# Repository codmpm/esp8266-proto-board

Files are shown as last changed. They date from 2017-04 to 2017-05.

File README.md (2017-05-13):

# ESP8266 minimal proto board / breadboard adaptor

This is a simple yet useful breadboard adaptor for the all famous ESP8266.

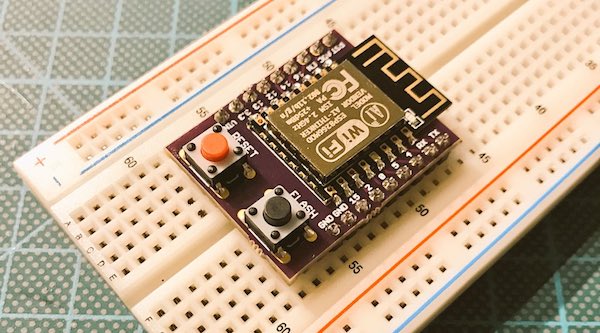
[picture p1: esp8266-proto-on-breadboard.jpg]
esp8266 proto board on breadboard


I've built this as the cheap chinese ones (white boards) are to wide to fit on a regular breadboard. To develop an own design you often don't need a full grown [Adafruit Huzzah](https://www.adafruit.com/product/2471), [Olimex MOD-WIFI-ESP8266-DEV](https://www.olimex.com/Products/IoT/MOD-WIFI-ESP8266-DEV/open-source-hardware) or similar ESP8266 devboard. Also the cheap chinese ones don't have a reset and/or flash button. I don't want to wire the needed resistors and a flash/reset button every time I'm putting an ESP on a breadboard.

Inside the folders you'll find the Eagle schematics and board files.

## Schematics
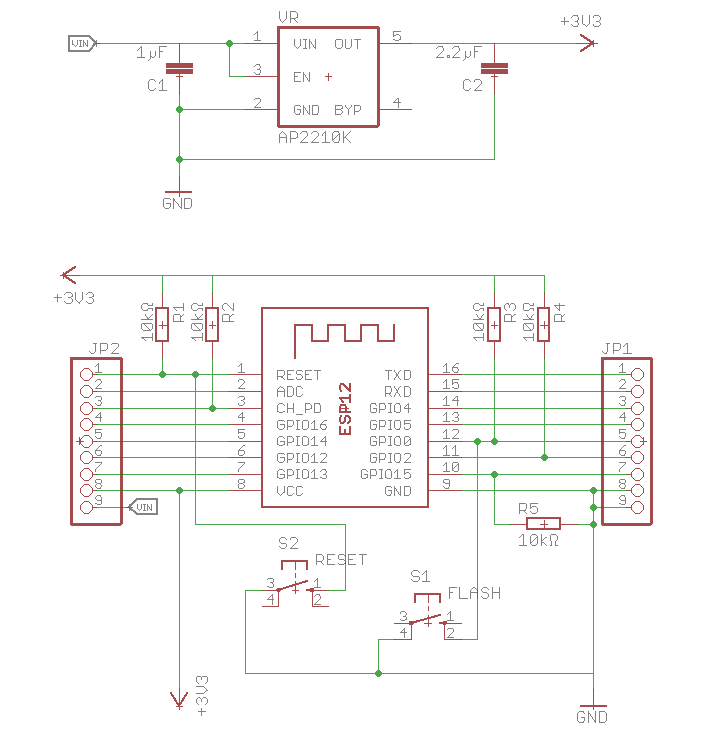
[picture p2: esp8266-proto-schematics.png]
esp8266 proto schematics


## Get it working...
You can simply solder some male headers and an ESP-12(E/F/Q), ESP-07 or ESP-14 on top of the board and are ready to go. 

The better way will be to at least solder some `10kΩ` resistors (`R1-R5`) to have the needed pull-ups/pull-downs to get the ESP working. Obviously it is also a good idea to solder the two push buttons so you have the reset and flash functionality. Then power it up with 3.3 Volts and you are good to go.

The buttons are the very common 6x6mm variant which goes by `switch-omron`. In Germany you can source the from [Reichelt](https://www.reichelt.de/Kurzhubtaster/TASTER-9302/3/index.html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) for example. But every electronics shop should have them in stock.

Optionally you can solder an [LDO](https://en.wikipedia.org/wiki/Low-dropout_regulator) to power the ESP with more than 3.3 Volts, as shown on the left side:

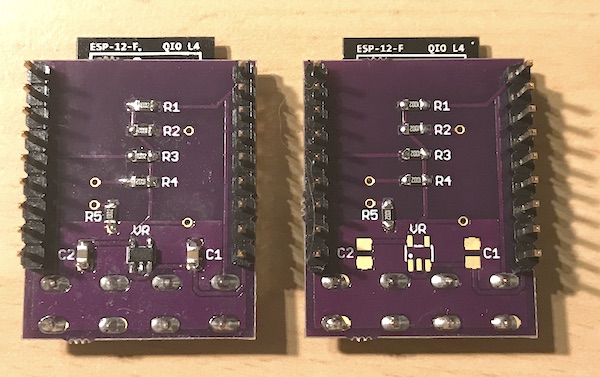
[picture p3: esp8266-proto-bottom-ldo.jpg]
esp8266 proto with and without ldo


## 0805 Version

You'll need 5 x SMD 0805 `10kΩ` resistors (`R1-R5`) and the two push-buttons. The 0805 resistors should be available from your prefered electronic store.

If you want to use the LDO you need the [AP2210K](https://www.diodes.com/assets/Datasheets/AP2210.pdf), a `SOT-23-5` LDO which can be powered with up to 13.2 Volts and only needs two capacitors (`C1/C2`) to run smooth. `C1` is `1µF`, `C2` is `2.2µF` in a 0805 package. It delivers up to 300mA which is fairly enough to power the ESP8266 - you have some room for periphals ;-)

You can use any other `SOT-32-5` LDO which supplies 3.3 Volts with at least 120-150mA, is satisfied with two capacitors and has the same pinout.

The boards can be ordered from [OSH Park](https://oshpark.com/shared_projects/u6mogmdg)



## 1206 Version
This is not finished yet and the repo only holds the work-in-progress version...

## Credits
Patrik Mayer, cod.m GmbH, 2017

Inspired by [tiny ESP8266 breakout](https://github.com/skorokithakis/tiny-ESP8266-breakout) from Stavros Korokithakis

## License
[CC-BY-SA](https://creativecommons.org/licenses/by-sa/3.0/)

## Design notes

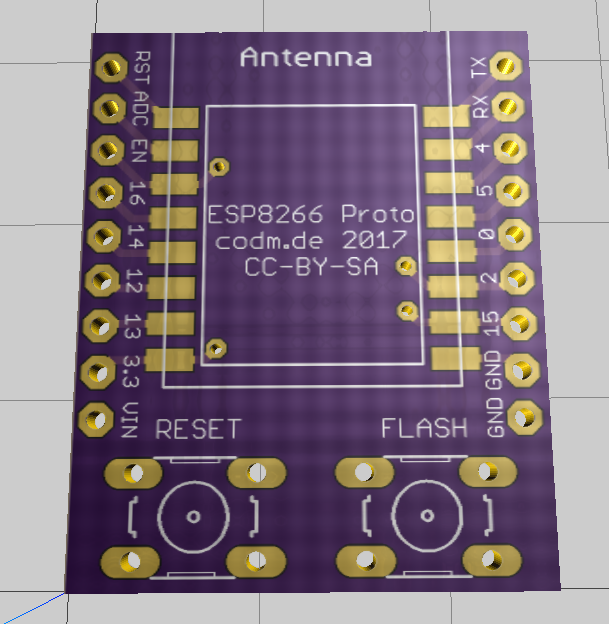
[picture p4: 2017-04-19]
esp8622-proto-board-0805.png

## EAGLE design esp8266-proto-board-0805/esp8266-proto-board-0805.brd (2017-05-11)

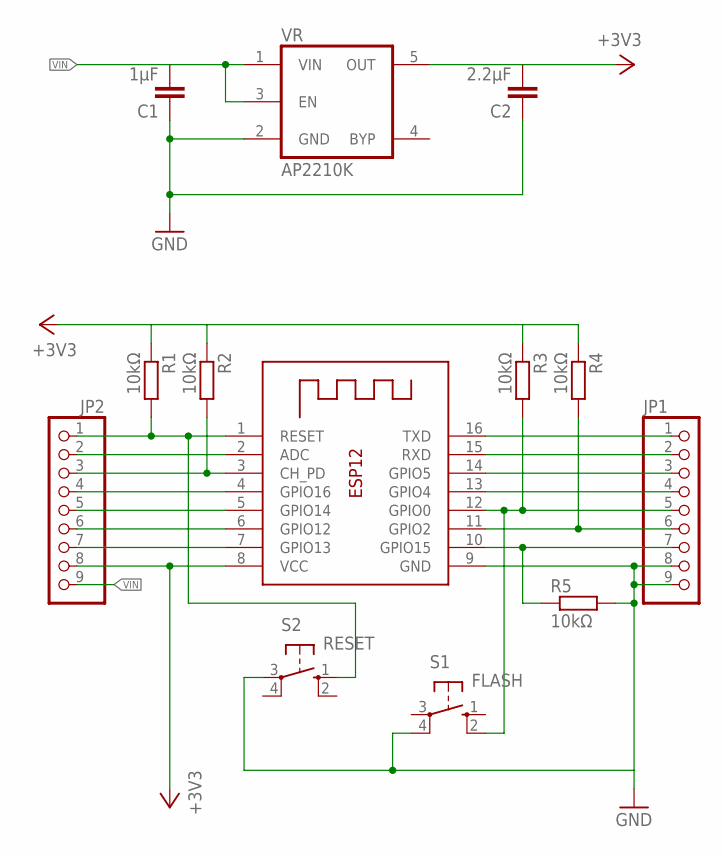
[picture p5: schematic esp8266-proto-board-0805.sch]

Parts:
C1: 1µF; C0805K
C2: 2.2µF; C0805K
JP1, JP2: PINHD-1X9; 1X09-BIG
R1, R2, R3, R4, R5: 10kΩ; R0805W
S1: FLASH; B3F-10XX
S2: RESET; B3F-10XX
U1: ESP-12
VR: AP2210K; SOT23-5

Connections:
+3V3: C2.2, JP2.8, R1.1, R2.1, R3.1, R4.1, U1.8 (VCC), VR.5 (OUT)
ADC: JP2.2, U1.2 (ADC)
CH_PD: JP2.3, R2.2, U1.3 (CH_PD)
GND: C1.1, C2.1, JP1.8, JP1.9, R5.2, S1.4 (P1), S2.3, U1.9 (GND), VR.2 (GND)
GPIO0: JP1.5, R3.2, S1.2 (S1), U1.12 (GPIO0)
GPIO2: JP1.6, R4.2, U1.11 (GPIO2)
GPIO4: JP1.4, U1.13 (GPIO4)
GPIO5: JP1.3, U1.14 (GPIO5)
GPIO12: JP2.6, U1.6 (GPIO12)
GPIO13: JP2.7, U1.7 (GPIO13)
GPIO14: JP2.5, U1.5 (GPIO14)
GPIO15: JP1.7, R5.1, U1.10 (GPIO15)
GPIO16: JP2.4, U1.4 (GPIO16)
RST: JP2.1, R1.2, S2.1 (S), U1.1 (RESET)
RX: JP1.2, U1.15 (RXD)
TX: JP1.1, U1.16 (TXD)
VIN: C1.2, JP2.9, VR.1 (VIN), VR.3 (EN)

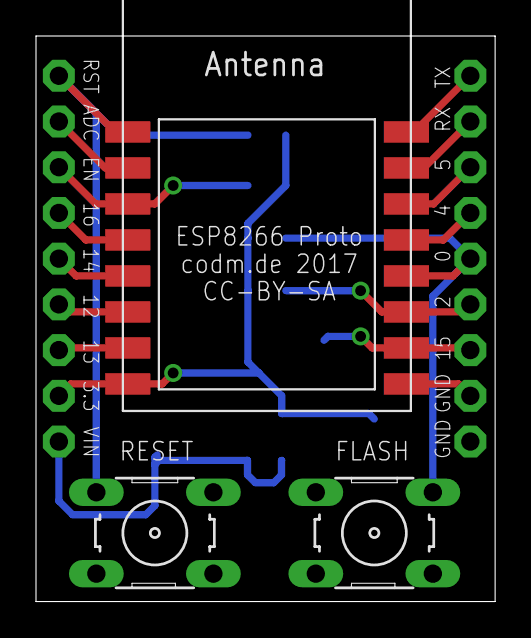
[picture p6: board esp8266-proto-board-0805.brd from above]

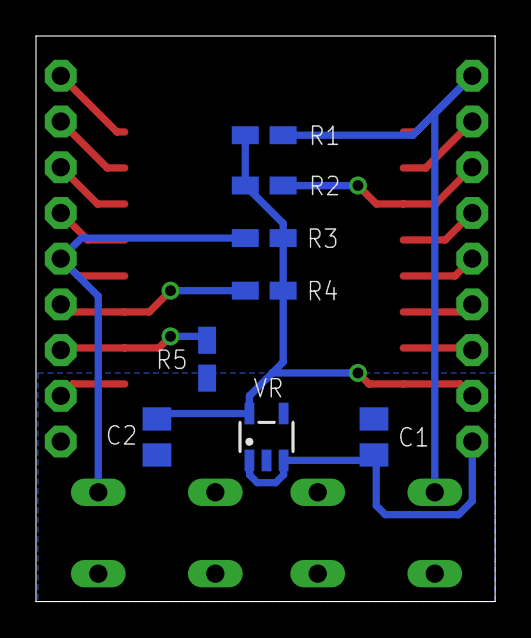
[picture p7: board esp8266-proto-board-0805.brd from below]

Board: 2 copper layers, 25.5 x 31.4 mm, 13 parts (8 on the bottom side), 17 nets.

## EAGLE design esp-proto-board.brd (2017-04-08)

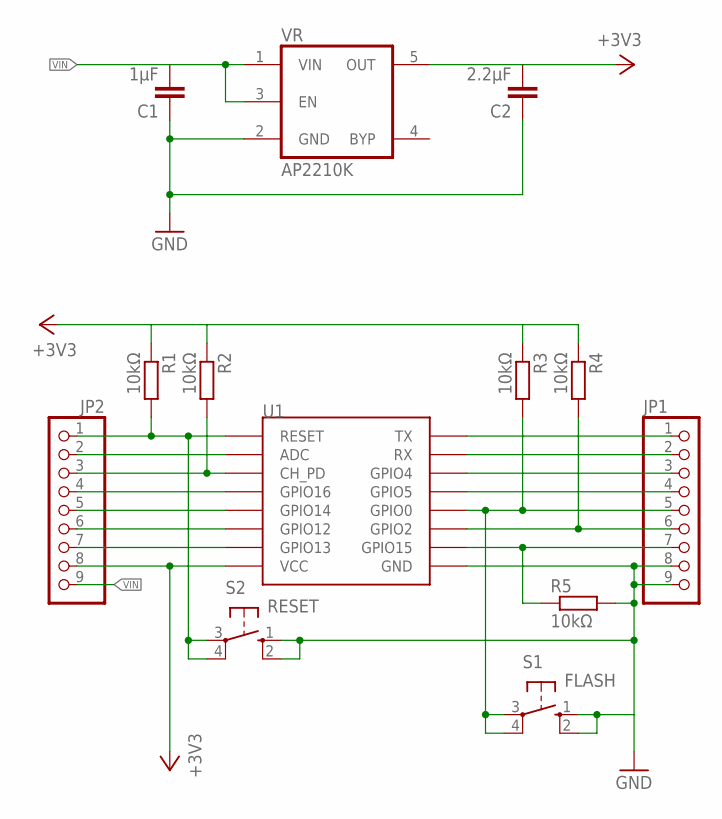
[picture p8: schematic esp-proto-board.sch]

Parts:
C1: 1µF; C0805K
C2: 2.2µF; C0805K
JP1, JP2: PINHD-1X9; 1X09
R1, R2, R3, R4, R5: 10kΩ; R0805W
S1: FLASH; B3F-10XX
S2: RESET; B3F-10XX
U1: ESP12SMD; ESP12-SMD
VR: AP2210K; SOT23-5

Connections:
+3V3: C2.2, JP2.8, R1.1, R2.1, R3.1, R4.1, U1.VCC, VR.5 (OUT)
ADC: JP2.2, U1.ADC
CH_PD: JP2.3, R2.2, U1.CH_PD
GND: C1.1, C2.1, JP1.8, JP1.9, R5.2, S1.1 (S), S1.2 (S1), S2.1 (S), S2.2 (S1), U1.GND, VR.2 (GND)
GPIO0: JP1.5, R3.2, S1.3, S1.4 (P1), U1.GPIO0
GPIO2: JP1.6, R4.2, U1.GPIO2
GPIO4: JP1.3, U1.GPIO4
GPIO5: JP1.4, U1.GPIO5
GPIO12: JP2.6, U1.GPIO12
GPIO13: JP2.7, U1.GPIO13
GPIO14: JP2.5, U1.GPIO14
GPIO15: JP1.7, R5.1, U1.GPIO15
GPIO16: JP2.4, U1.GPIO16
RST: JP2.1, R1.2, S2.3, S2.4 (P1), U1.RESET
RX: JP1.2, U1.RXD0 (RX)
TX: JP1.1, U1.TXD0 (TX)
VIN: C1.2, JP2.9, VR.1 (VIN), VR.3 (EN)

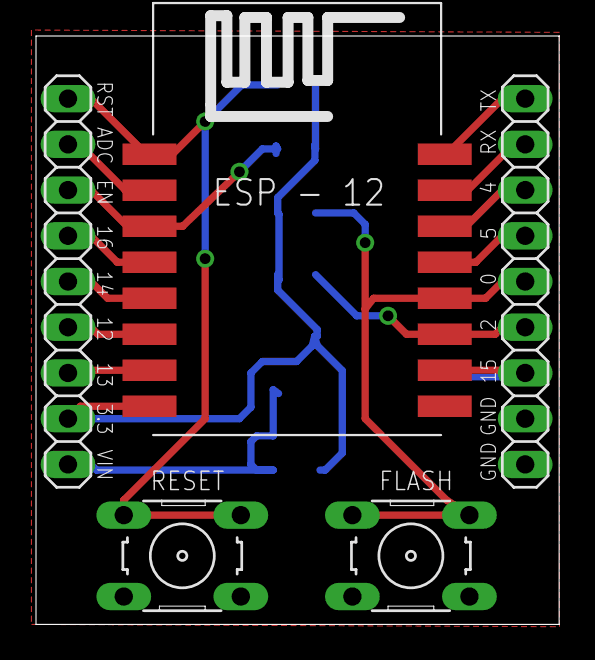
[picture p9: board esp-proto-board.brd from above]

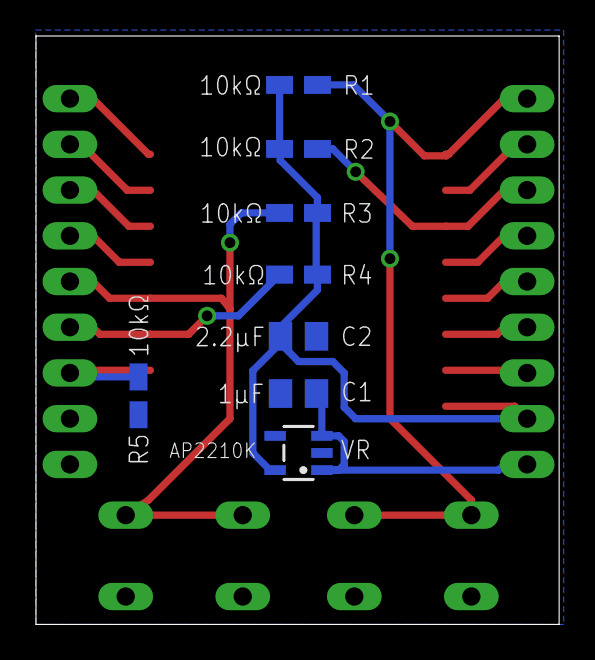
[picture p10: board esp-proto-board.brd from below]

Board: 2 copper layers, 29.1 x 32.7 mm, 13 parts (8 on the bottom side), 17 nets.

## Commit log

2017-04-08 moved bValues to bNames
    [esp-proto-board.brd]
2017-04-08 added board images
2017-04-19 reworked 0805 version with better footprint
    [esp8266-proto-board-0805.brd, esp8266-proto-board-0805.sch, esp8266-proto-board-1206.brd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]
2017-04-19 moved capacitors
    [esp8266-proto-board-0805.brd]
2017-05-11 fixed mixed up gpio5/gpio4 in esp-lib part
    [esp8266-proto-board-0805.brd, esp8266-proto-board-0805.sch]
